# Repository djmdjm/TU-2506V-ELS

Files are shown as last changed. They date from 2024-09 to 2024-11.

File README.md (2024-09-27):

# Electronic Leadscrew for Optimum TU-2506V

This is a project to build an Electronic Leadscrew (ELS) for my bench
lathe, an Optimum TU-2506V. There are other lathes on the market that
seem to be based on the same casting (e.g. the Weiss WBL250F) that
might be compatible.

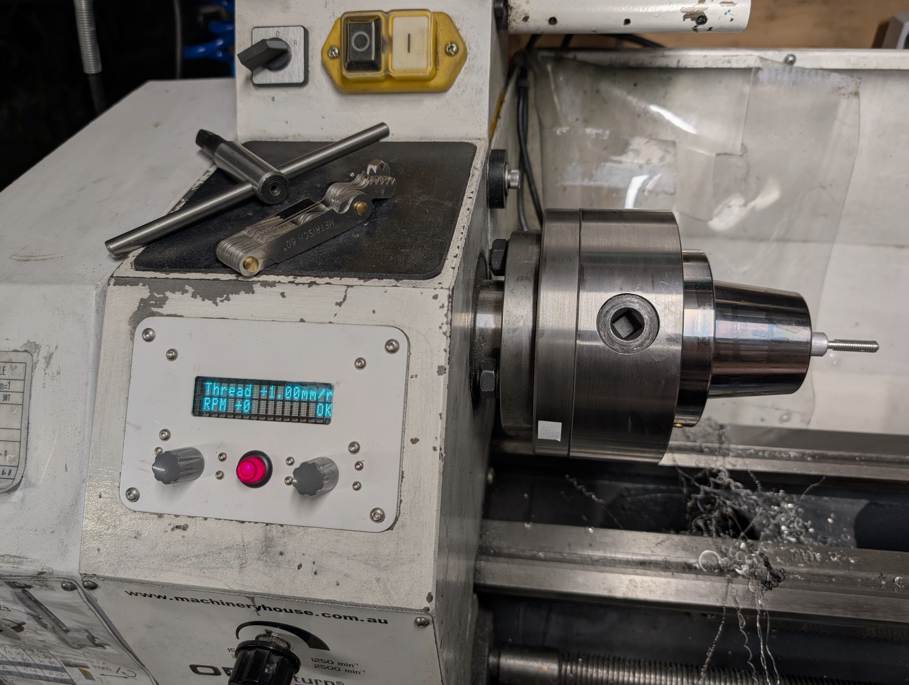
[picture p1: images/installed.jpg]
installed ELS controller


The project contains CAD designs for the mechanical parts, schematics,
PCB designs and firmware for the control board. More build photos
[here](https://photos.google.com/share/AF1QipOmF3oVsJtj0tLDA7D8ZUFRA7_QTG3Cf1XSVP2GjohUuVMBAQHxomHKcaGD1ETOJg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).

## Caveat

This works fine for me, but I'm just some guy on the internet with
little or no mechanical, electronic or software engineering training. 
There is no warranty for any of this, no guarantee that it will work,
no guarantee that it won't destroy your lathe, no promise that the
software won't crash in the middle of a job and scrap your part, etc.

Many of the mechanical pieces were manually made and even the
ones I CNC'd or had fabricated received some modifications that
aren't reflected in the CAD files. If you want to use this as the
basis of your own ELS, then be prepared to do some modifications of
your own.

## What you'll need (software)

The mechanical CAD designs were done in
[FreeCAD](https://www.freecad.org/) 0.21. For the parts that I CNC'd
myself, I also used FreeCAD's CAM processor to generate the G-Code.

The control boards was designed in [KiCAD](https://www.kicad.org/)
version 8 and were fabricated at JLCPCB. The PCB files have LCSC
annotations for automated assembly of the (few) SMT components.

The firmware for the control board was written in Rust using the
[stm32f4xx_hal](https://github.com/stm32-rs/stm32f4xx-hal) package.
I used rustc 1.81.0, but other versions might work too.

## What you'll need (hardware)

This lists only the main components. There are many small parts that
should be obvious from the CAD files, not to mention custom parts that
you'll need to make yourself or have fabricated.

The controller was designed around a
[STM32F411 "black pill"](https://www.dfrobot.com/product-2338.html) board.
These are also easily and cheaply available from hobbyist electronics
suppliers and from Ebay/Aliexpress.

The display is a
[Newhaven M0216SD‐162SDAR2-1](https://au.mouser.com/ProductDetail/Newhaven-Display/M0216SD-162SDAR2-1?qs=3vk7fz9CmNxwBN2LYkSmDA%3D%3D)
vacuum fluorescent display that I ordered from Mouser - this is a
fairly expensive part, but I love the aesthetics of a VFD.

The rest of the BOM for the controller can be extracted from the
KiCAD files for each of the respective boards. I mostly used parts that
I had on hand, so there are some odd choices in places.

The controller needs a 24VDC power supply at about 250mA in addition to
whatever the servo control needs. I used a Meanwell DIN rail mount PSU.

The servo motor I used a
[Teknic Clearpath CPM-SDSK-2331S-ELS](https://teknic.com/model-info/CPM-SDSK-2331S-ELS/).
Again, this is a fairly expensive choice and a cheaper stepper
motor + controller would probably do fine. The Clearpath drive does
have some very nice advantages over plain steppers or even cheap
closed-loop stepper drives. Whatever drive you choose, it obviously
needs to fit (NEMA 23 was close to the limit on my lathe) and you'll
need to provide a suitable power supply for it.

The spindle encoder I used was an
[Omron E6B2-CWZ1X](https://www.ia.omron.com/product/item/2382/). These are
ridiculously expensive if you buy them from anywhere reputable, but very
cheap on Ebay or Aliexpress.

The timing pulleys and belt used to connect the servo to the
leadscrew are standard HTD 5M parts. I got mine from PT Parts
([pulleys](https://www.ptparts.com.au/products/category/ALL/-12-5M-15--5m-15-htd-timing-pulleys):
20-5M-15F 40-5M-15F,
[belt](https://www.ptparts.com.au/products/category/ALL/-225-5M-15--5m-15-timing-belts): 350-5M-15),
but they should be fairly standard.

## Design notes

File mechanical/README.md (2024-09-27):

# CAD files for mechanical parts

This directory contains CAD files for some of the mechanical parts and
assemblies. They were all designed in FreeCAD 0.21. Some components
require plugins, e.g. the gears workbench and the fasteners workbench.

If you plan on using the CAM jobs included in some of the components,
you will definitiely need to change the machine model and tooling.

## Motor mounting plate

The `lathe_leadscrew_motor_plate.FCStd` file is the CAD for the servo
motor mounting plate. It's designed for a NEMA 23 servo or stepper.
It's a very basic part that is probably best laser-cut.

I did need to modify this plate a little to fit the space, but cutting
off a couple of the corners. This is not reflected in the CAD file.

This plate does double duty as a template to mark the locations of the
holes that need to be drilled and tapped into the lathe casting.

## Encoder assembly

The `lathe_leadscrew_encoder_plate.FCStd` is the assembly that couples
the encoder to the spindle. There's a few bespoke parts in here: a main
plate that holds the shaft bearing, a separate plate that mounts the
encoder, some standoffs to separate the two and a spindle that is driven
by a gear that couples to the spindle. Note the flexible coupler here
comes with the encoder.

I built the main plate as a weldment from laser-cut sheet metal and a
turned part that I then re-bored for concentricity on the CNC mill.

At first I used one of the original change gears on this assembly but,
like most change gears, it was annoyingly noisy. I ended up casting the
gear in polyurethane, which helped insofar as PU is better acoustically
than metal, but still wasn't amazing. If I ever rebuild the lathe spindle,
I'll replace the gear with another timing pulley.

## Controller assembly

`lathe_els_panel.FCStd` contains the CAD for the controller assembly, which
consists of a front panel in 2mm sheet metal, a protective lens machined from
2mm acrylic and a bunch of off-the-shelf standoffs and fasteners.

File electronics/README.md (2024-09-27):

# Controller schematics and PCB designs

This directory contains the schematics and PCB CAD files for the controller
boards. To fit in the available space in the lathe casting they are designed
as a stack.

The `mcu/` subdirectory contains the designs for the MCU carrier board, which
basically exists to route signals from the STM32F411 Black Pill board to the
adjacent ones via headers. The character VFD display also connects to this
board via extended headers.

The `pwr_io/` subdirectory has the design for the isolated power and I/O board.
It has a couple of modular DC-DC converters that provide an isolated supply
to the MCU and display, and a separate isolated supply for the spindle encoder
and servo control lines.

The `ui/` subdirectory has the design for the carrier board for the rotary
encoders used on the front panel (you'll need two of these). These connect
via cables terminated in IDC connectors on the MCU board.

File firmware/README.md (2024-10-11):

# Firmware for Electronic Leadscrew

This is the firmware for the electronic leadscrew controller board.
It's core task is receiving pulses from the encoder connected to the
lathe spindle and emitting pulses to drive the servo motor attached to
the lathe's leadscrew.

The user interface is a 16x2 VFD character display, two rotary encoders
with integrated pushbuttons and a dedicated pushbutton.

The firmware is written in Rust targetting the STM32F411 MCU. If you've
installed Rust using rustup, then you can get the toolchain and required
tools using:

```shell
rustup target add thumbv7em-none-eabihf
cargo install cargo-binutils
cargo install probe-rs-tools
```

For a good background on Rust embedded development, how to set up openocd,
install prerequisite system packages, etc. the
[Embedded Rust Book](https://docs.rust-embedded.org/book/) is a great start.

To build the firmware, run `cargo build` from this directory. If you have
the board attached using a ST-Link dongle and have `openocd` running,
then `cargo run` will attempt to download the firmware to the board and
run it under gdb. The `flash.sh` script will burn a release version of the
firmware to the board.

## Modes

The firmware supports a number of operating modes and a debug mode.
Switching between modes is done using one of the control rotary encoders,
with the other rotary encoder being used to set parameters within that mode
such as feed rate or thread pitch. Mode changes, and some parameter changes
will be ignored unless the spindle is stationery.

The controller starts in the `Servo off` mode, which unsurprisingly disables
the servo drive. The `Feed` mode is intended for general cutting applications,
and runs the leadscrew to advance at a configured rate (in mm) per spindle
revolution. Two threading modes are available: `Thread`, which performs metric
(mm/rev) threading and `Thread Im` which does imperial (TPI) threading.

The debug mode can be accessed by pressing the mode encoder's button for a
couple of seconds. This mode has a number of pages, accessible via the mode
wheel, that show various internal debugging parameters. Debug mode can be
exited by holding down the mode button again.

## Notes

The control loop for the ELS is quite simplistic - the mainloop runs
continuously and (depending on operating mode) generates servo control pulses
as quickly as it receives encoder pulses. It uses mostly-precomputed 64-bit
math to simplify (as 32.32 fixed point) to simplify calculations. Once of the
nice things about having a 100MHz MCU is not having to worry too much about
the cycle cost here.

There is one interrupt handler hooked up to one of the timers that runs a 1KHz
monotonic counter that is used to drive the 10Hz display update and the RPM
sampling/smoothing.

The most time-critical component of the firmware is the servo pulse generation.
At high RPM and high feed rates, the firmware needs to be able to quickly emit
lots of pulses. Conversely, the servo requires a maximum pulse frequency of
500KHz. I couldn't get this running fast enough in Rust, so the actual pulse
generation is written in assembly.

Motor, encoder, leadscrew and gear/pulley ratio constants are in `src/main.rs`.
You'll almost certainly need to edit these.

The calculations are unashamedly metric and inch leadscrews are not supported.

There's currently no detection of situations where the control loop can't keep
up (i.e. can't generate servo pulses fast enough for a given spindle RPM).
I'm fairly sure this situation isn't possible with the parameters I've used,
and I've certainly not encountered it in use (though admittedly I haven't
tried to run the leadscrew at 4mm/rev and 1500RPM).

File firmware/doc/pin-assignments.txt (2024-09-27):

Encoder inputs
PA0  - T2_CH1 - ENC1a (spindle)
PA1  - T2_CH2 - ENC1b (spindle)
PA6  - T9_CH1 - ENC2a (feed)
PA7  - T9_CH2 - ENC2b (feed)
PC15 - GPIOC  - ENC2 button (feed)
PB6  - T4_CH1 - ENC3a (mode)
PB7  - T4_CH2 - ENC3b (mode)
PB8  - GPIOB  - ENC3 button (mode)

Button inputs
PA4  - GPIOA  - Button 1

Other inputs
PA3 - GPIOA  - Motor HLFB input

Outputs
PC13 - GPIOC  - Board LED
PB10 - GPIOB  - Motor Enable output
PB1  - GPIOB  - Motor Direction output
PB0  - GPIOB  - Motor Step output

VFD I/O
PA15 - GPIOA  - DB0
PA12 - GPIOA  - DB1
PA8  - GPIOA  - DB2
PB14 - GPIOB  - DB3
PB13 - GPIOB  - DB4
PB12 - GPIOB  - DB5
PB15 - GPIOB  - DB6
PA11 - GPIOA  - DB7
PB4  - GPIOB  - E
PB9  - GPIOB  - RW
PB3  - GPIOB  - RS

Free
PA2  - GPIOA  -
PA5  - GPIOA  - 
PA9  - GPIOA  - TX1
PA10 - GPIOA  - RX1 (w/ 100k pull up to make BOOT0 reliable)
PB2  - GPIOB  -
PB5  - GPIOB  -
PC14 - GPIOC  - (nb. low current limit)

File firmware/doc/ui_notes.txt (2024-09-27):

Notes to plan UI on 16x2 character LCD/VFD.

available space

+----------------+
|0123456789abcdef|
|0123456789abcdef|
+----------------+

Normal feed mode

+----------------+
|Feed  +100μm/r  |
|RPM   3000    OK| (OK | WARN | ERR)
+----------------+

Constant feed mode

+----------------+
|Feed  +400mm/min|
|RPM   3000   ERR| (OK | WARN | ERR)
+----------------+

Threading mode (metric)

+----------------+
|Thread +1.00mm/R|
|RPM    300  WARN| (OK | WARN | ERR)
+----------------+

Threading mode (imperial)

+----------------+
|Thread +24TPI   |
|RPM    300    OK| (OK | WARN | ERR)
+----------------+

Slotting mode

+----------------+
|Slot   400mm/min|
|Depth  100mm RDY| (RDY | GO+ | GO- | ERR)
+----------------+

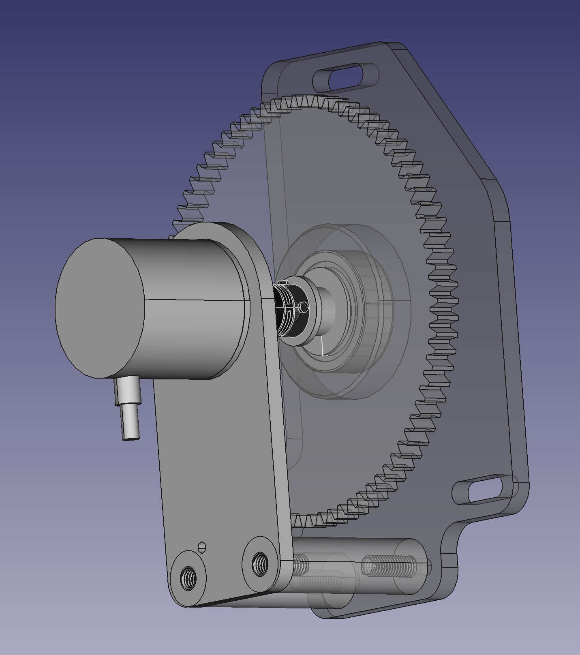
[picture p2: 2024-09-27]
mechanical/lathe_leadscrew_encoder_plate.png

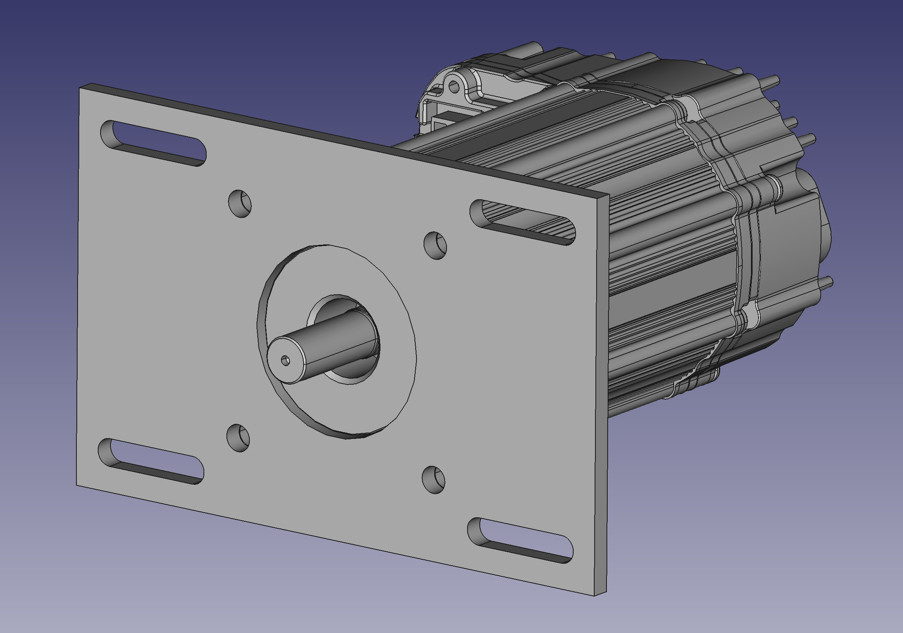
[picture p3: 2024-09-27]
mechanical/lathe_leadscrew_motor_plate.png

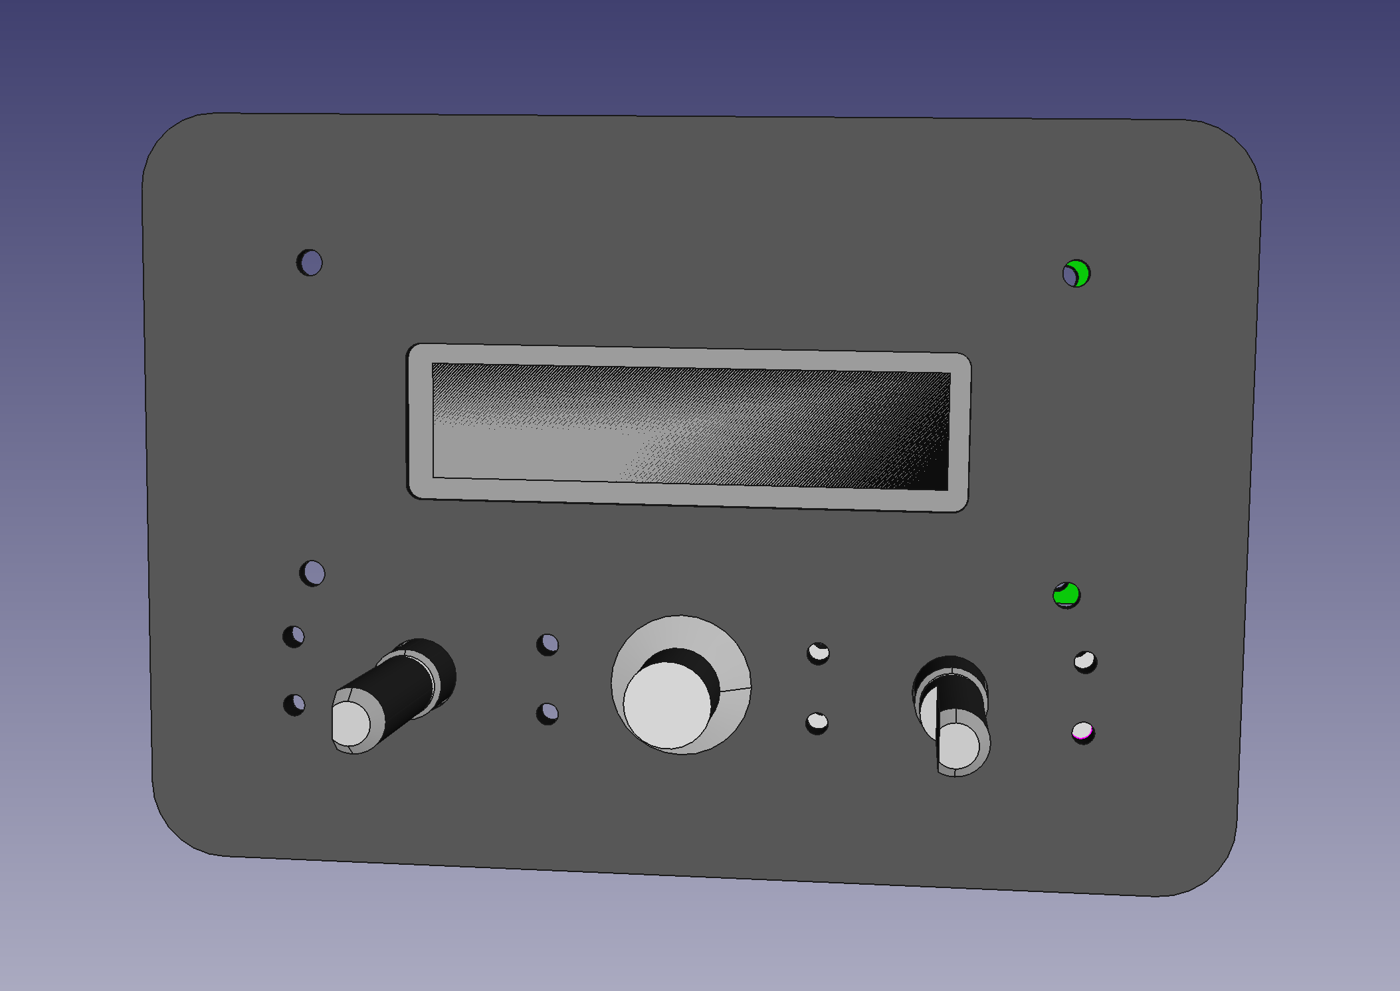
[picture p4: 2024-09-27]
mechanical/lathe_els_panel.png

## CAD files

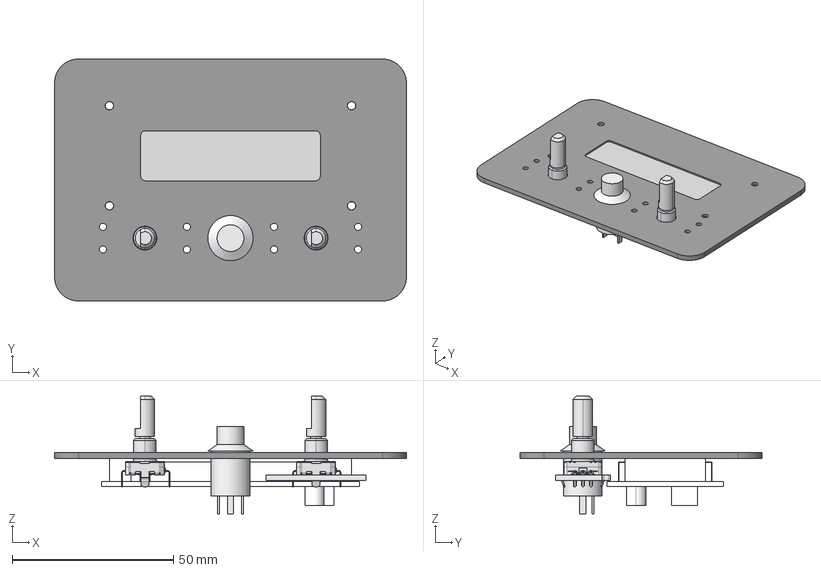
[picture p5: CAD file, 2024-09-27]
mechanical/lathe_els_panel.FCStd
109.0 x 75.0 x 36.5 mm
M0216SD-162SDAR2-1
Panel
Coverglass
Encoder1
Button
Encoder2
PCB

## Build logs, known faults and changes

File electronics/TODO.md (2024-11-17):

If I ever redesign the electronics, here are changes to make:

* Use vertical entry screw terminals so ferrules can clear lathe casting.
* More spare GPIO inputs/outputs.
* Another spare encoder channel would be nice too...
* Use JST-style connectors for encoders/button; IDC sockets were a fail.
* GPIO to control button light.
* Isolated RS-485 for spindle motor control and telemetry.
* See if I can cram everything onto one bespoke board.

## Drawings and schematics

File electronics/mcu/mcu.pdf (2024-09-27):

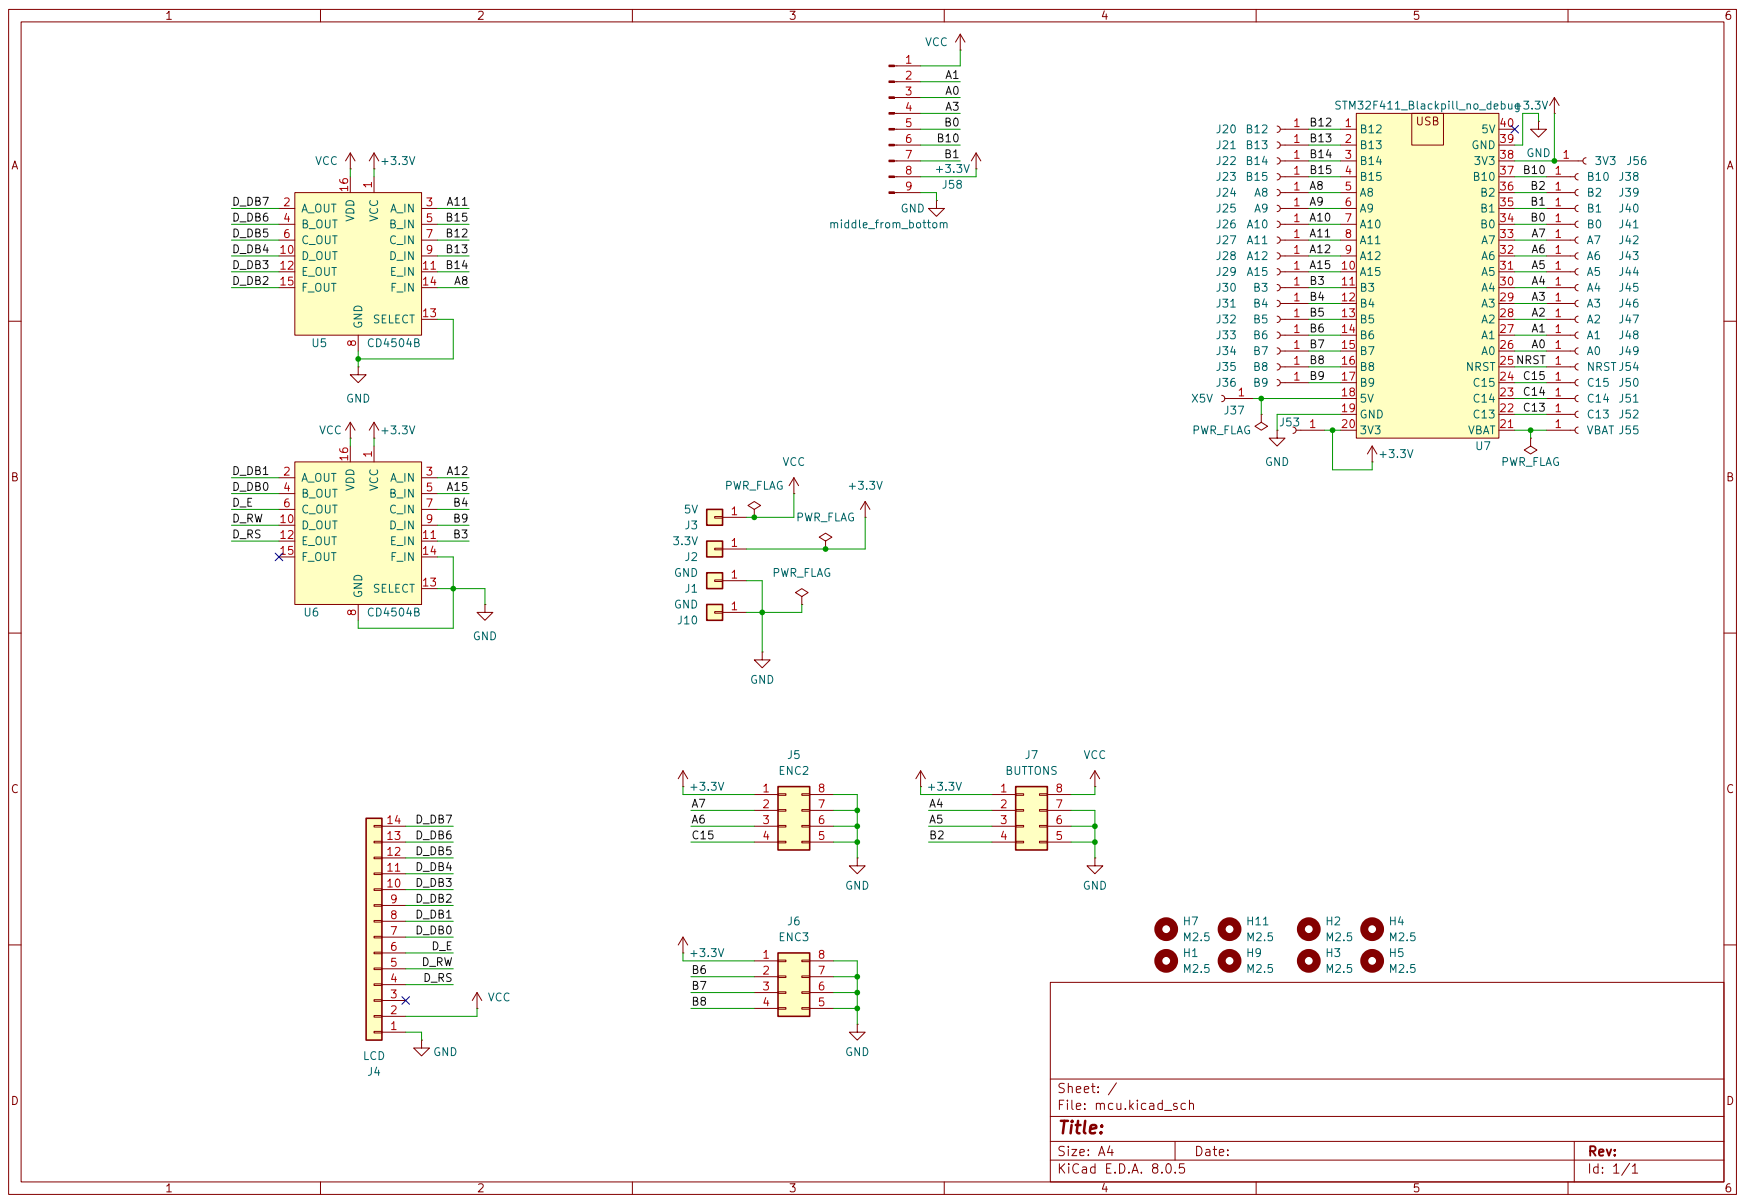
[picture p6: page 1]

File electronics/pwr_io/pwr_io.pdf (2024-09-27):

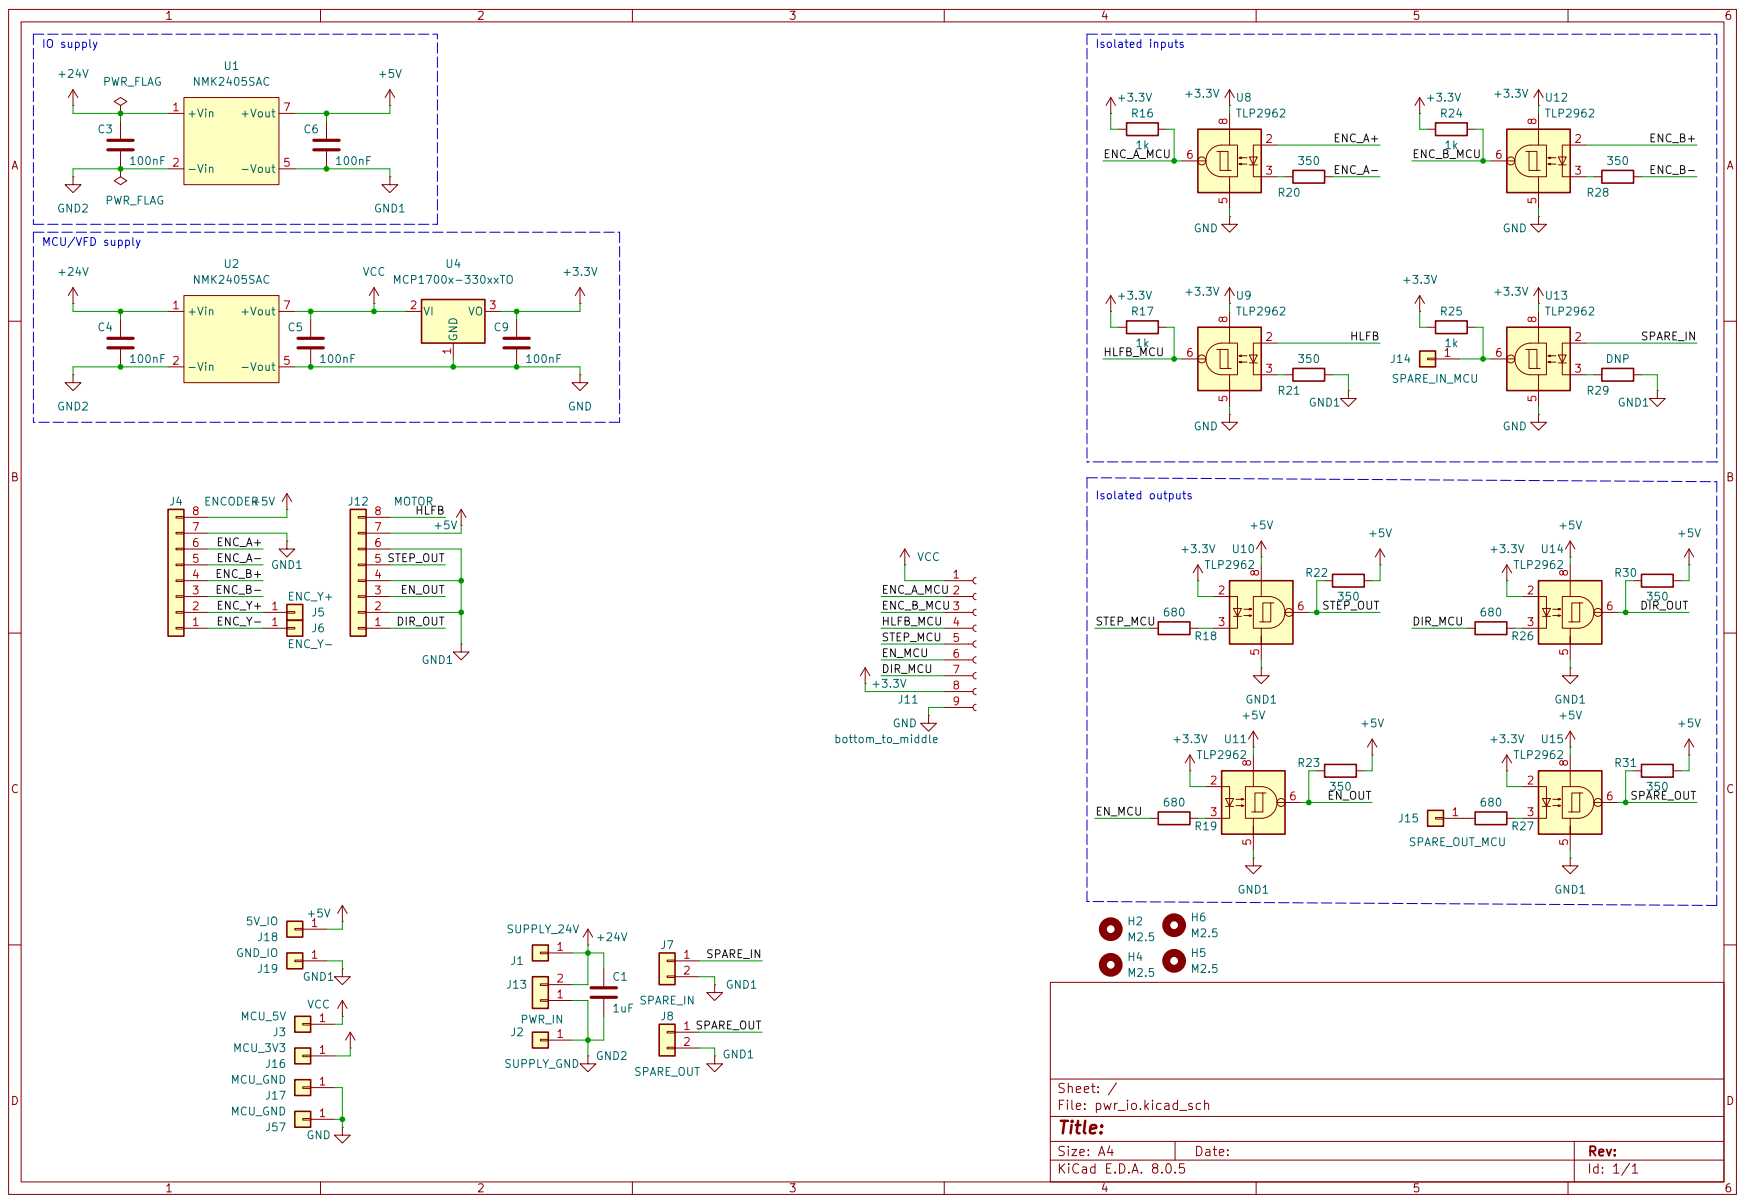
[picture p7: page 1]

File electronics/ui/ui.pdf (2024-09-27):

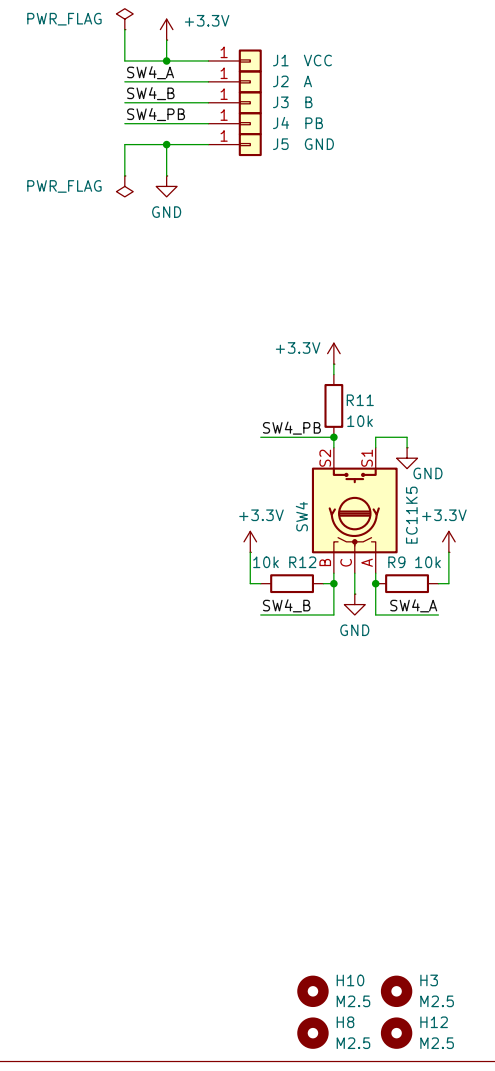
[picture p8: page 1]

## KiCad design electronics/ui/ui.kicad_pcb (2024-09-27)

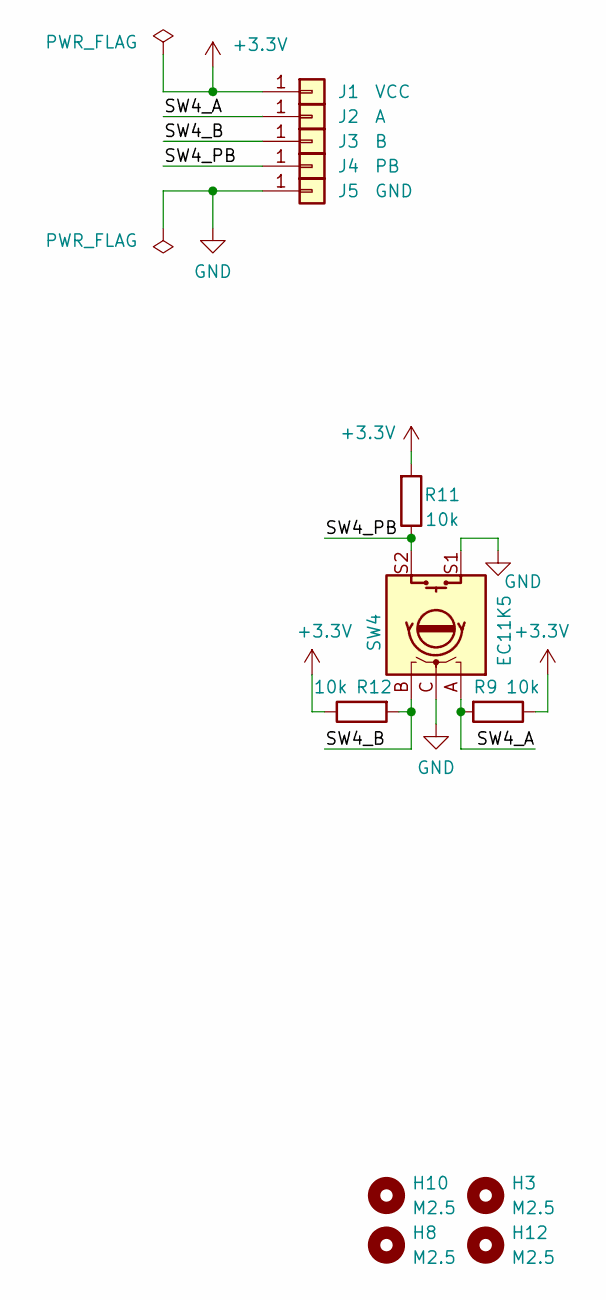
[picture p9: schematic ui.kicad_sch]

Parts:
H3, H8, H10, H12: M2.5; MountingHole_2.2mm_M2
J1: VCC; TestPoint_THTPad_D1.0mm_Drill0.5mm
J2: A; TestPoint_THTPad_D1.0mm_Drill0.5mm
J3: B; TestPoint_THTPad_D1.0mm_Drill0.5mm
J4: PB; TestPoint_THTPad_D1.0mm_Drill0.5mm
J5: GND; TestPoint_THTPad_D1.0mm_Drill0.5mm
R9, R11, R12: 10k; R_0805_2012Metric; LCSC C17414
SW4: EC11K5; EC11K15

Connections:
+3.3V: J1.1, R9.1, R11.2, R12.1
/SW4_A: J2.1, R9.2, SW4.A
/SW4_B: J3.1, R12.2, SW4.B
/SW4_PB: J4.1, R11.1, SW4.S2
GND: J5.1, SW4.C, SW4.S1

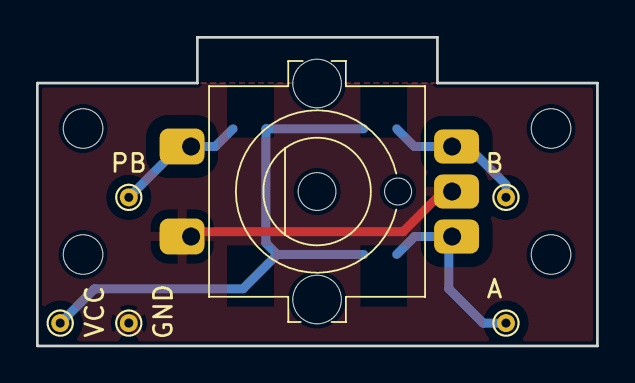
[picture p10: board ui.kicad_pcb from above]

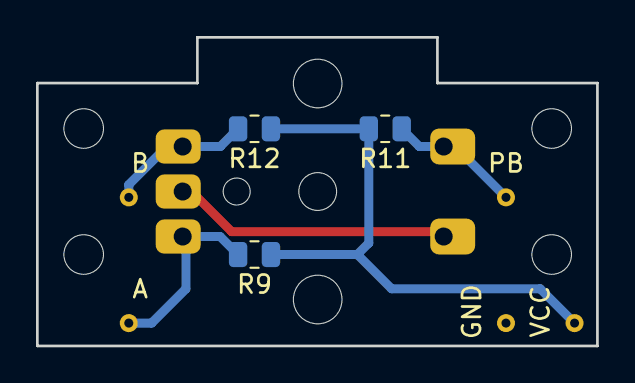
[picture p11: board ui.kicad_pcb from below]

Board: 2 copper layers, 31.1 x 17.1 mm, 13 parts (3 on the bottom side), 5 nets.

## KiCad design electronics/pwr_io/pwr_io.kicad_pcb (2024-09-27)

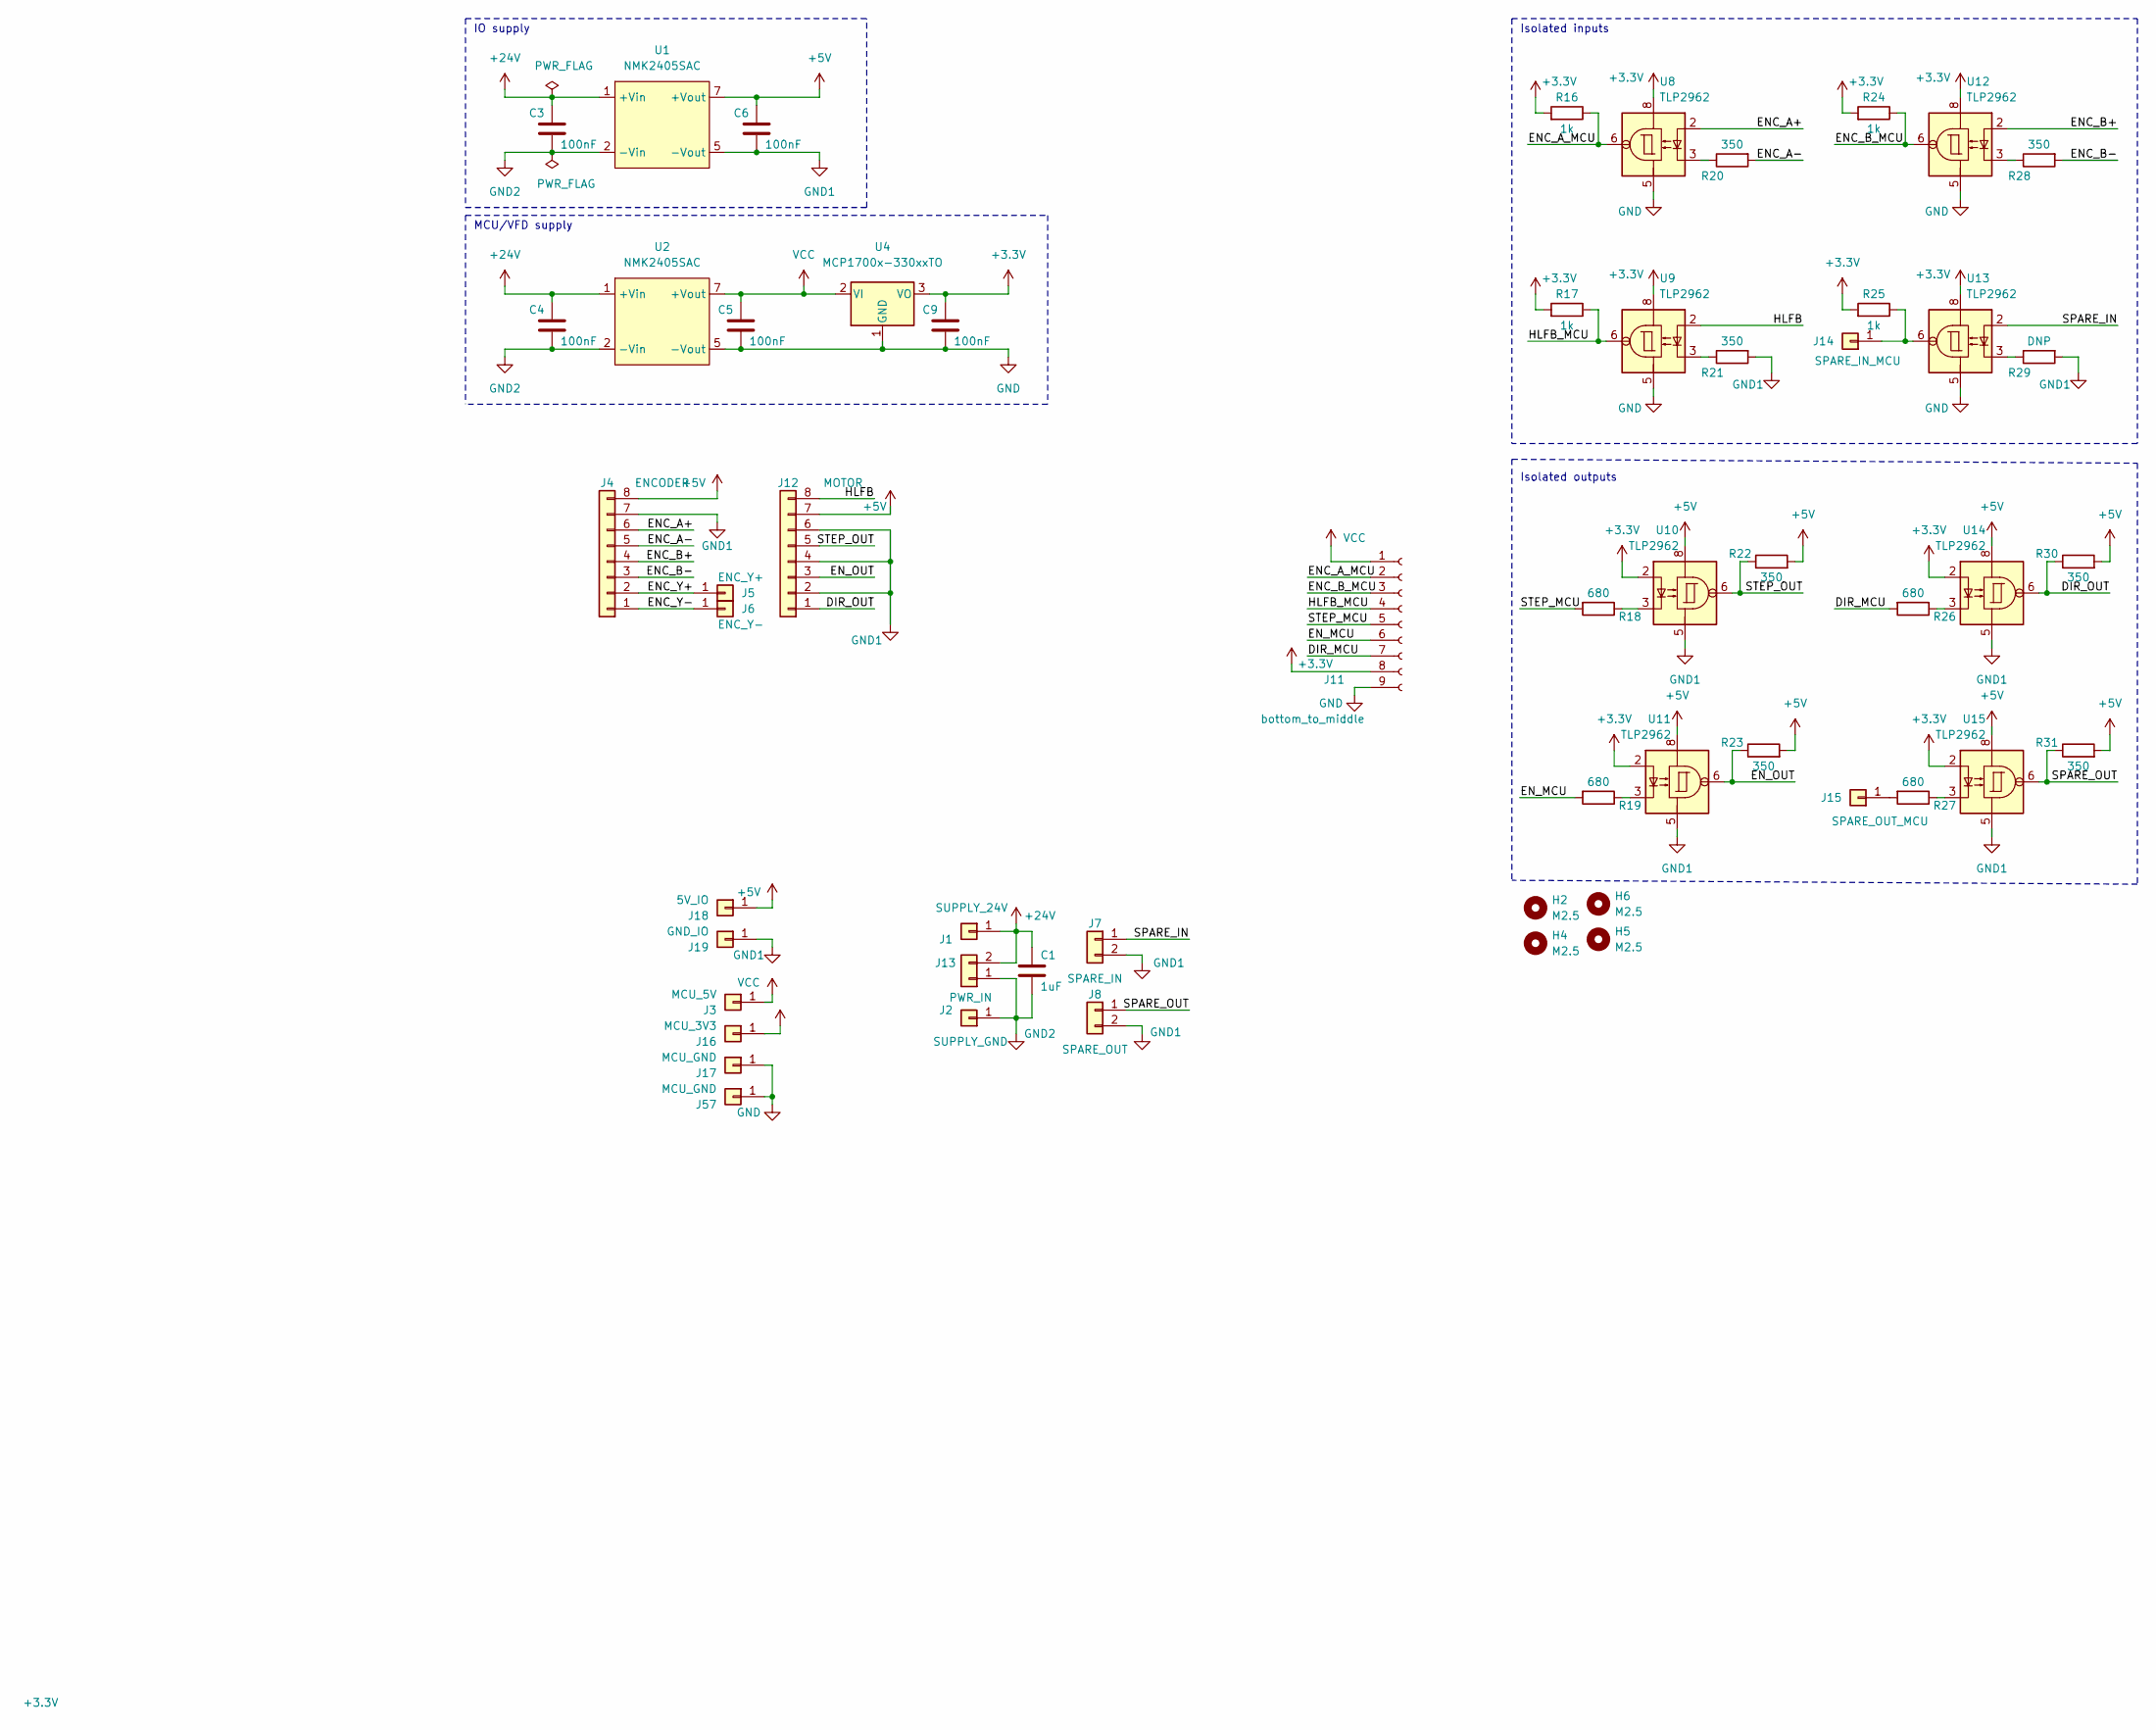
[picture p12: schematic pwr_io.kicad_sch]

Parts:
C1: 1uF; C_0805_2012Metric; LCSC C28323
C3, C4, C5, C6, C9: 100nF; C_0805_2012Metric; LCSC C28233
H2, H4, H5, H6: M2.5; MountingHole_2.7mm_M2.5
J1: SUPPLY_24V; TestPoint_THTPad_D1.5mm_Drill0.7mm
J2: SUPPLY_GND; TestPoint_THTPad_D1.5mm_Drill0.7mm
J3: MCU_5V; TestPoint_THTPad_D1.5mm_Drill0.7mm
J4: ENCODER; TerminalBlock_Phoenix_MKDS-1,5-8_1x08_P5.00mm_Horizontal
J5: ENC_Y+; TestPoint_THTPad_D1.5mm_Drill0.7mm
J6: ENC_Y-; TestPoint_THTPad_D1.5mm_Drill0.7mm
J7: SPARE_IN; TerminalBlock_Phoenix_MKDS-1,5-2_1x02_P5.00mm_Horizontal
J8: SPARE_OUT; TerminalBlock_Phoenix_MKDS-1,5-2_1x02_P5.00mm_Horizontal
J11: bottom_to_middle; PinHeader_1x09_P2.54mm_Vertical
J12: MOTOR; TerminalBlock_Phoenix_MKDS-1,5-8_1x08_P5.00mm_Horizontal
J13: PWR_IN; TerminalBlock_Phoenix_MKDS-1,5-2_1x02_P5.00mm_Horizontal
J14: SPARE_IN_MCU; TestPoint_THTPad_D1.5mm_Drill0.7mm
J15: SPARE_OUT_MCU; TestPoint_THTPad_D1.5mm_Drill0.7mm
J16: MCU_3V3; TestPoint_THTPad_D1.5mm_Drill0.7mm
J17, J57: MCU_GND; TestPoint_THTPad_D1.5mm_Drill0.7mm
J18: 5V_IO; TestPoint_THTPad_D1.5mm_Drill0.7mm
J19: GND_IO; TestPoint_THTPad_D1.5mm_Drill0.7mm
R16, R17, R24, R25: 1k; R_0805_2012Metric; LCSC C17513
R18, R19, R26, R27: 680; R_0805_2012Metric; LCSC C93658
R20, R21, R22, R23, R28, R30, R31: 350; R_0805_2012Metric; LCSC C245312
R29: DNP; R_0805_2012Metric
U1, U2: NMK2405SAC; NMK_single_output
U4: MCP1700x-330xxTO; TO-92_Inline
U8, U9, U10, U11, U12, U13, U14, U15: TLP2962; DIP-8_W7.62mm

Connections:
+3.3V: C9.1, J11.8, J16.1, R16.2, R17.2, R24.2, R25.2, U4.3 (VO), U8.8, U9.8, U10.2, U11.2, U12.8, U13.8, U14.2, U15.2
+5V: C6.1, J4.8, J12.7, J18.1, R22.2, R23.2, R30.2, R31.2, U1.7 (+Vout), U10.8, U11.8, U14.8, U15.8
+24V: C1.1, C3.1, C4.1, J1.1, J13.2, U1.1 (+Vin), U2.1 (+Vin)
/DIR_MCU: J11.7, R26.2
/DIR_OUT: J12.1, R30.1, U14.6
/ENC_A+: J4.6, U8.2
/ENC_A-: J4.5, R20.2
/ENC_A_MCU: J11.2, R16.1, U8.6
/ENC_B+: J4.4, U12.2
/ENC_B-: J4.3, R28.2
/ENC_B_MCU: J11.3, R24.1, U12.6
/ENC_Y+: J4.2, J5.1
/ENC_Y-: J4.1, J6.1
/EN_MCU: J11.6, R19.2
/EN_OUT: J12.3, R23.1, U11.6
/HLFB: J12.8, U9.2
/HLFB_MCU: J11.4, R17.1, U9.6
/SPARE_IN: J7.1, U13.2
/SPARE_OUT: J8.1, R31.1, U15.6
/STEP_MCU: J11.5, R18.2
/STEP_OUT: J12.5, R22.1, U10.6
GND: C5.2, C9.2, J11.9, J17.1, J57.1, U2.5 (-Vout), U4.1 (GND), U8.5, U9.5, U12.5, U13.5
GND1: C6.2, J4.7, J7.2, J8.2, J12.2, J12.4, J12.6, J19.1, R21.2, R29.2, U1.5 (-Vout), U10.5, U11.5, U14.5, U15.5
GND2: C1.2, C3.2, C4.2, J2.1, J13.1, U1.2 (-Vin), U2.2 (-Vin)
unnamed: J14.1, R25.1, U13.6
unnamed: J15.1, R27.2
unnamed: R18.1, U10.3
unnamed: R19.1, U11.3
unnamed: R20.1, U8.3
unnamed: R21.1, U9.3
unnamed: R26.1, U14.3
unnamed: R27.1, U15.3
unnamed: R28.1, U12.3
unnamed: R29.1, U13.3
VCC: C5.1, J3.1, J11.1, U2.7 (+Vout), U4.2 (VI)

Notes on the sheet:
Isolated outputs
Isolated inputs
IO supply
MCU/VFD supply

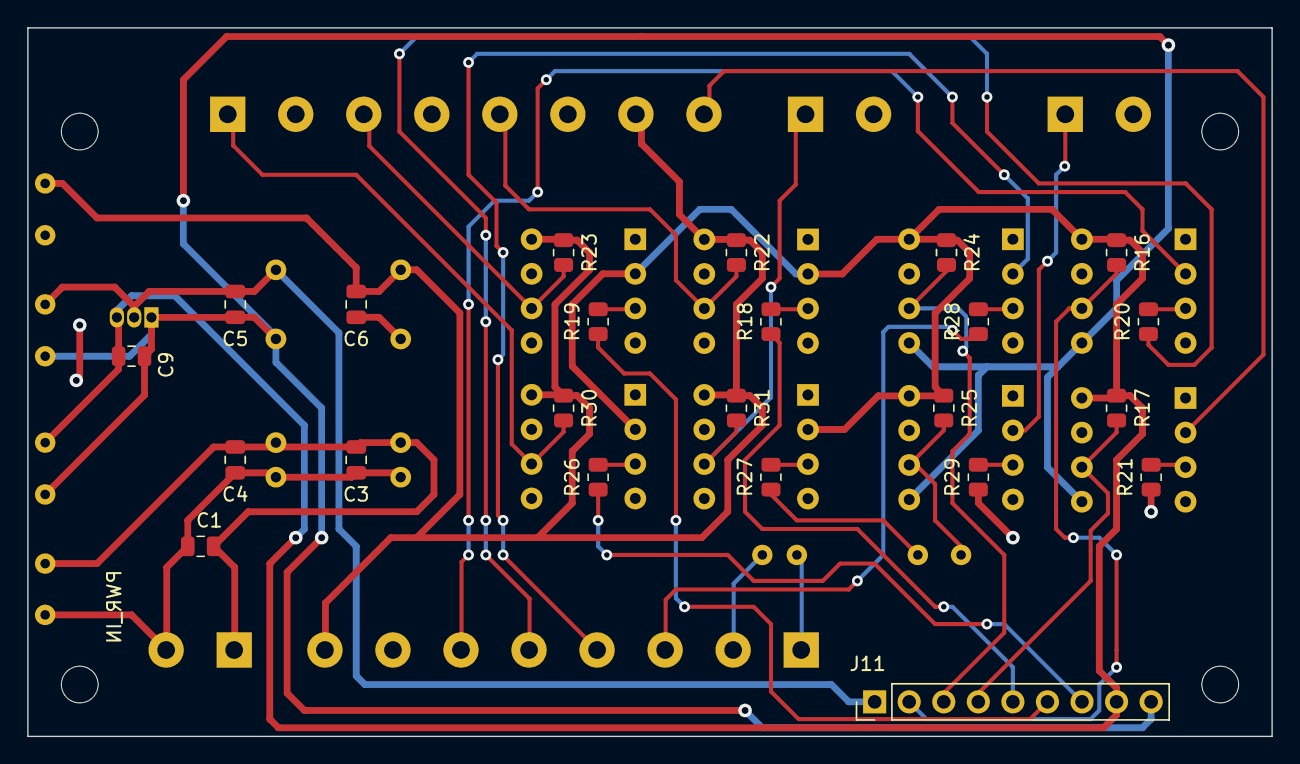
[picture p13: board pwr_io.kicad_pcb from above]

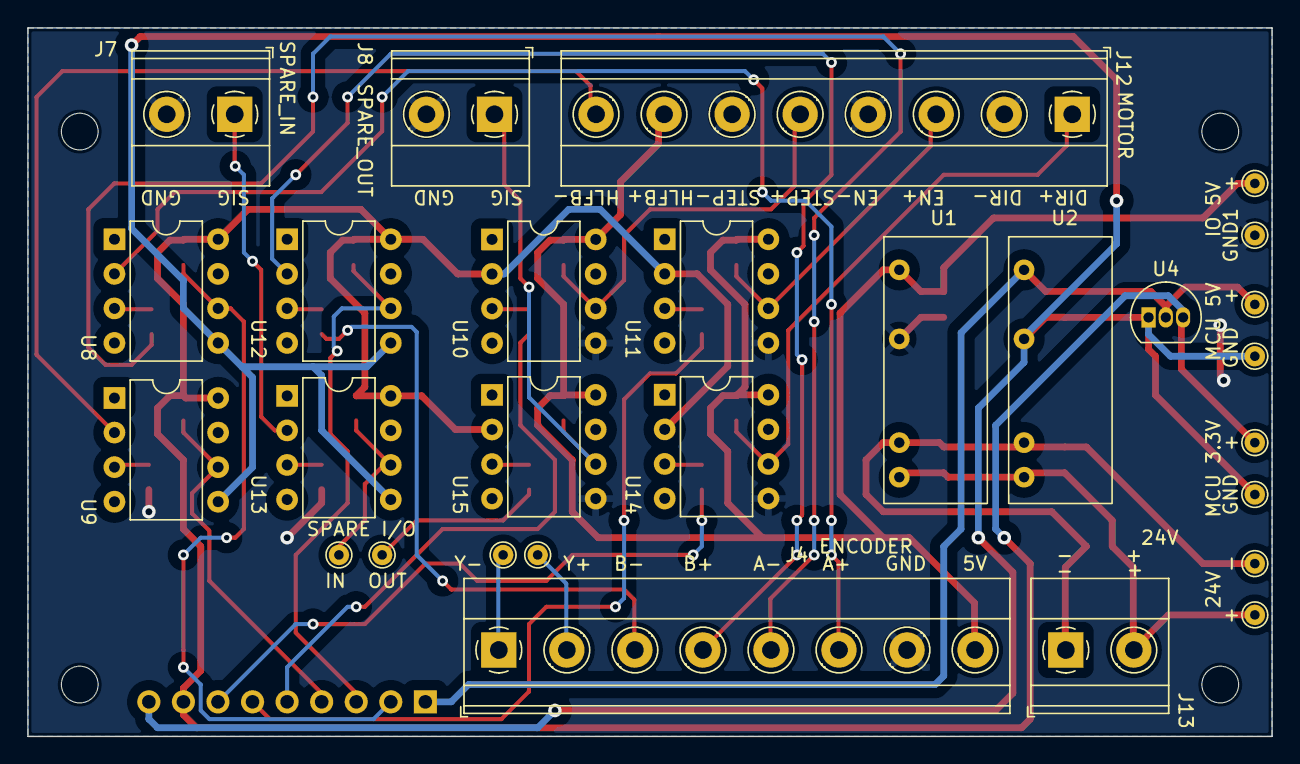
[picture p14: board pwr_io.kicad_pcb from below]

Board: 2 copper layers, 91.4 x 52.1 mm, 55 parts (28 on the bottom side), 35 nets.

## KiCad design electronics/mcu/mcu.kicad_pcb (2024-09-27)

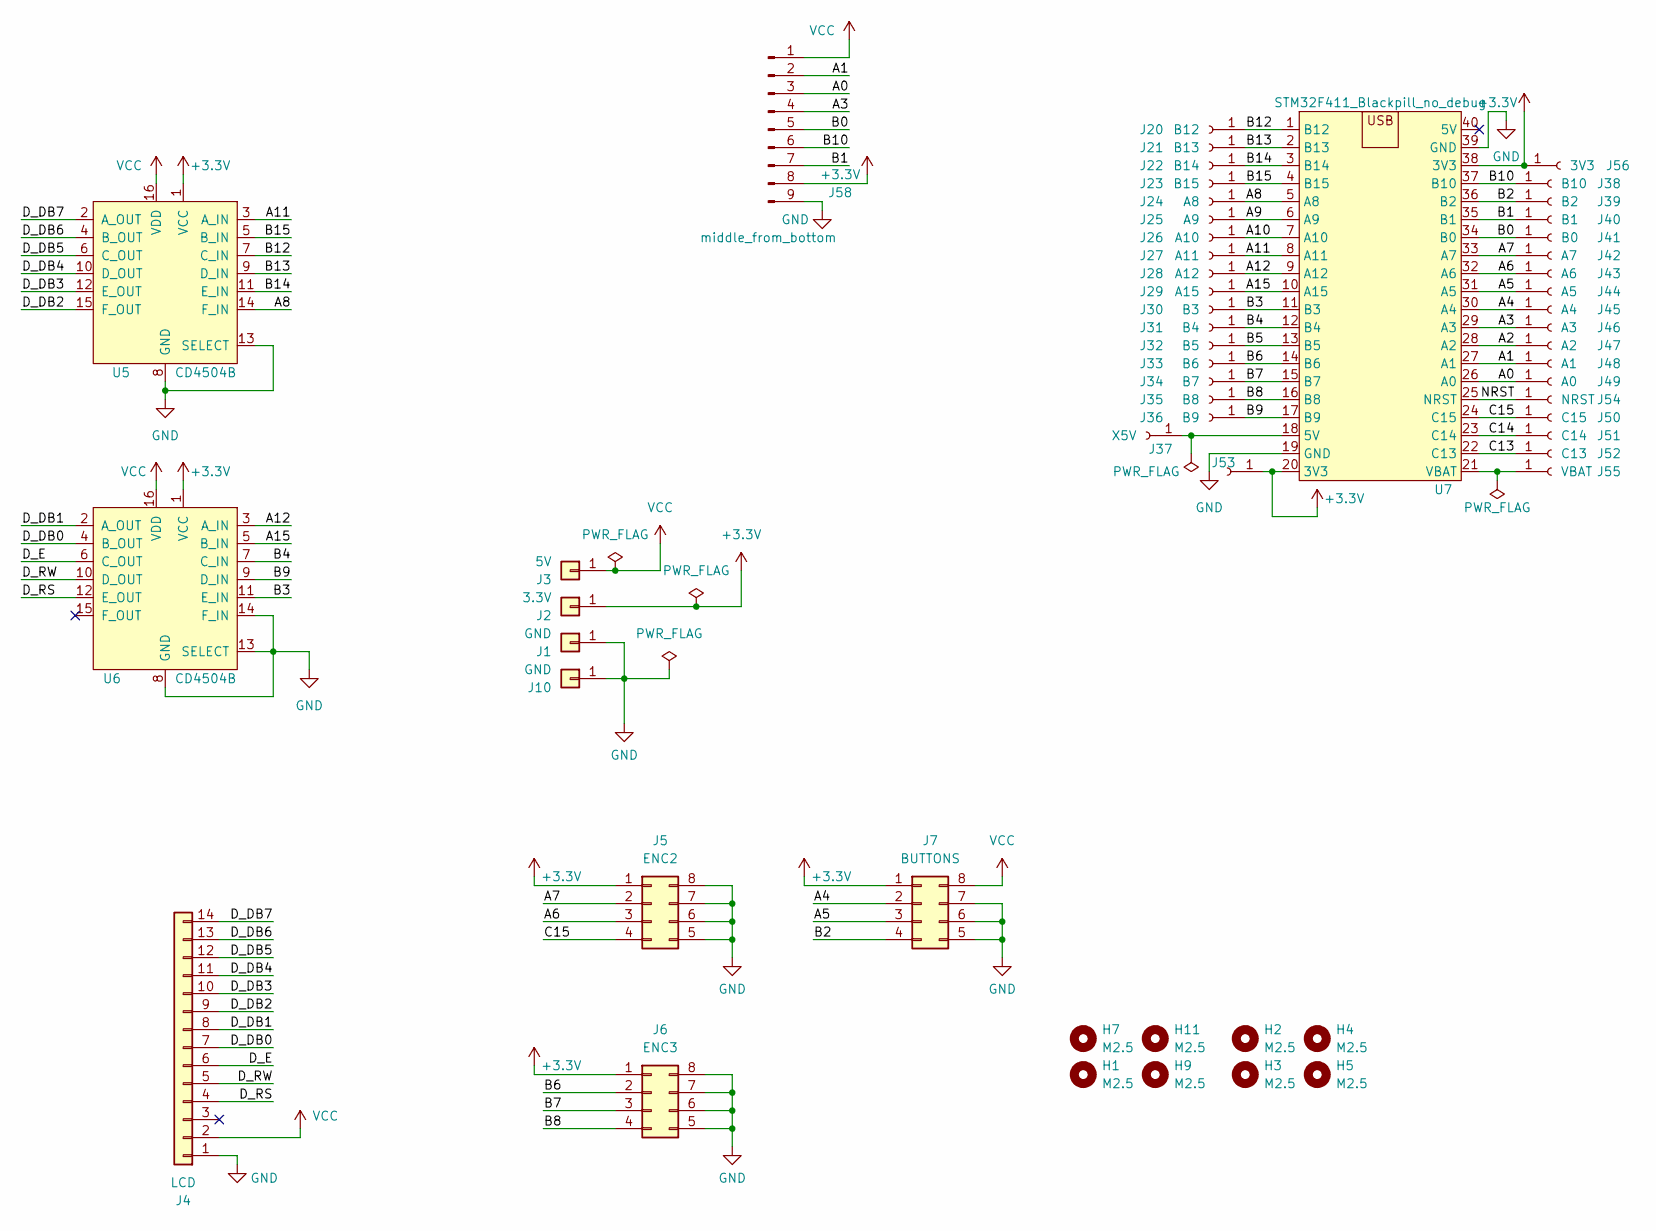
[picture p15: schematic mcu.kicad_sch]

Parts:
H1, H2, H3, H4, H5, H7, H9, H11: M2.5; MountingHole_2.7mm_M2.5
J1, J10: GND; TestPoint_THTPad_D1.5mm_Drill0.7mm
J2: 3.3V; TestPoint_THTPad_D1.5mm_Drill0.7mm
J3: 5V; TestPoint_THTPad_D1.5mm_Drill0.7mm
J4: LCD; PinHeader_1x14_P2.54mm_Vertical
J5: ENC2; IDC-Header_2x04_P2.54mm_Vertical
J6: ENC3; IDC-Header_2x04_P2.54mm_Vertical
J7: BUTTONS; IDC-Header_2x04_P2.54mm_Vertical
J20: B12; TestPoint_THTPad_D1.5mm_Drill0.7mm
J21: B13; TestPoint_THTPad_D1.5mm_Drill0.7mm
J22: B14; TestPoint_THTPad_D1.5mm_Drill0.7mm
J23: B15; TestPoint_THTPad_D1.5mm_Drill0.7mm
J24: A8; TestPoint_THTPad_D1.5mm_Drill0.7mm
J25: A9; TestPoint_THTPad_D1.5mm_Drill0.7mm
J26: A10; TestPoint_THTPad_D1.5mm_Drill0.7mm
J27: A11; TestPoint_THTPad_D1.5mm_Drill0.7mm
J28: A12; TestPoint_THTPad_D1.5mm_Drill0.7mm
J29: A15; TestPoint_THTPad_D1.5mm_Drill0.7mm
J30: B3; TestPoint_THTPad_D1.5mm_Drill0.7mm
J31: B4; TestPoint_THTPad_D1.5mm_Drill0.7mm
J32: B5; TestPoint_THTPad_D1.5mm_Drill0.7mm
J33: B6; TestPoint_THTPad_D1.5mm_Drill0.7mm
J34: B7; TestPoint_THTPad_D1.5mm_Drill0.7mm
J35: B8; TestPoint_THTPad_D1.5mm_Drill0.7mm
J36: B9; TestPoint_THTPad_D1.5mm_Drill0.7mm
J37: X5V; TestPoint_THTPad_D1.5mm_Drill0.7mm
J38: B10; TestPoint_THTPad_D1.5mm_Drill0.7mm
J39: B2; TestPoint_THTPad_D1.5mm_Drill0.7mm
J40: B1; TestPoint_THTPad_D1.5mm_Drill0.7mm
J41: B0; TestPoint_THTPad_D1.5mm_Drill0.7mm
J42: A7; TestPoint_THTPad_D1.5mm_Drill0.7mm
J43: A6; TestPoint_THTPad_D1.5mm_Drill0.7mm
J44: A5; TestPoint_THTPad_D1.5mm_Drill0.7mm
J45: A4; TestPoint_THTPad_D1.5mm_Drill0.7mm
J46: A3; TestPoint_THTPad_D1.5mm_Drill0.7mm
J47: A2; TestPoint_THTPad_D1.5mm_Drill0.7mm
J48: A1; TestPoint_THTPad_D1.5mm_Drill0.7mm
J49: A0; TestPoint_THTPad_D1.5mm_Drill0.7mm
J50: C15; TestPoint_THTPad_D1.5mm_Drill0.7mm
J51: C14; TestPoint_THTPad_D1.5mm_Drill0.7mm
J52: C13; TestPoint_THTPad_D1.5mm_Drill0.7mm
J53, J56: 3V3; TestPoint_THTPad_D1.5mm_Drill0.7mm
J54: NRST; TestPoint_THTPad_D1.5mm_Drill0.7mm
J55: VBAT; TestPoint_THTPad_D1.5mm_Drill0.7mm
J58: middle_from_bottom; PinSocket_1x09_P2.54mm_Vertical
U5, U6: CD4504B; DIP-16_W7.62mm
U7: STM32F411_Blackpill_no_debug; BlackPill_V3_no_debug

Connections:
+3.3V: J2.1, J5.1, J6.1, J7.1, J53.1, J56.1, J58.8, U5.1 (VCC), U6.1 (VCC), U7.20 (3V3), U7.38 (3V3)
/A0: J49.1, J58.3, U7.26 (A0)
/A1: J48.1, J58.2, U7.27 (A1)
/A2: J47.1, U7.28 (A2)
/A3: J46.1, J58.4, U7.29 (A3)
/A4: J7.2, J45.1, U7.30 (A4)
/A5: J7.3, J44.1, U7.31 (A5)
/A6: J5.3, J43.1, U7.32 (A6)
/A7: J5.2, J42.1, U7.33 (A7)
/A8: J24.1, U5.14 (F_IN), U7.5 (A8)
/A9: J25.1, U7.6 (A9)
/A10: J26.1, U7.7 (A10)
/A11: J27.1, U5.3 (A_IN), U7.8 (A11)
/A12: J28.1, U6.3 (A_IN), U7.9 (A12)
/A15: J29.1, U6.5 (B_IN), U7.10 (A15)
/B0: J41.1, J58.5, U7.34 (B0)
/B1: J40.1, J58.7, U7.35 (B1)
/B2: J7.4, J39.1, U7.36 (B2)
/B3: J30.1, U6.11 (E_IN), U7.11 (B3)
/B4: J31.1, U6.7 (C_IN), U7.12 (B4)
/B5: J32.1, U7.13 (B5)
/B6: J6.2, J33.1, U7.14 (B6)
/B7: J6.3, J34.1, U7.15 (B7)
/B8: J6.4, J35.1, U7.16 (B8)
/B9: J36.1, U6.9 (D_IN), U7.17 (B9)
/B10: J38.1, J58.6, U7.37 (B10)
/B12: J20.1, U5.7 (C_IN), U7.1 (B12)
/B13: J21.1, U5.9 (D_IN), U7.2 (B13)
/B14: J22.1, U5.11 (E_IN), U7.3 (B14)
/B15: J23.1, U5.5 (B_IN), U7.4 (B15)
/C13: J52.1, U7.22 (C13)
/C14: J51.1, U7.23 (C14)
/C15: J5.4, J50.1, U7.24 (C15)
/D_DB0: J4.7, U6.4 (B_OUT)
/D_DB1: J4.8, U6.2 (A_OUT)
/D_DB2: J4.9, U5.15 (F_OUT)
/D_DB3: J4.10, U5.12 (E_OUT)
/D_DB4: J4.11, U5.10 (D_OUT)
/D_DB5: J4.12, U5.6 (C_OUT)
/D_DB6: J4.13, U5.4 (B_OUT)
/D_DB7: J4.14, U5.2 (A_OUT)
/D_E: J4.6, U6.6 (C_OUT)
/D_RS: J4.4, U6.12 (E_OUT)
/D_RW: J4.5, U6.10 (D_OUT)
/NRST: J54.1, U7.25 (NRST)
GND: J1.1, J4.1, J5.5, J5.6, J5.7, J5.8, J6.5, J6.6, J6.7, J6.8, J7.5, J7.6, J7.7, J10.1, J58.9, U5.8 (GND), U5.13 (SELECT), U6.8 (GND), U6.13 (SELECT), U6.14 (F_IN), U7.19 (GND), U7.39 (GND)
unnamed: J37.1, U7.18 (5V)
unnamed: J55.1, U7.21 (VBAT)
VCC: J3.1, J4.2, J7.8, J58.1, U5.16 (VDD), U6.16 (VDD)

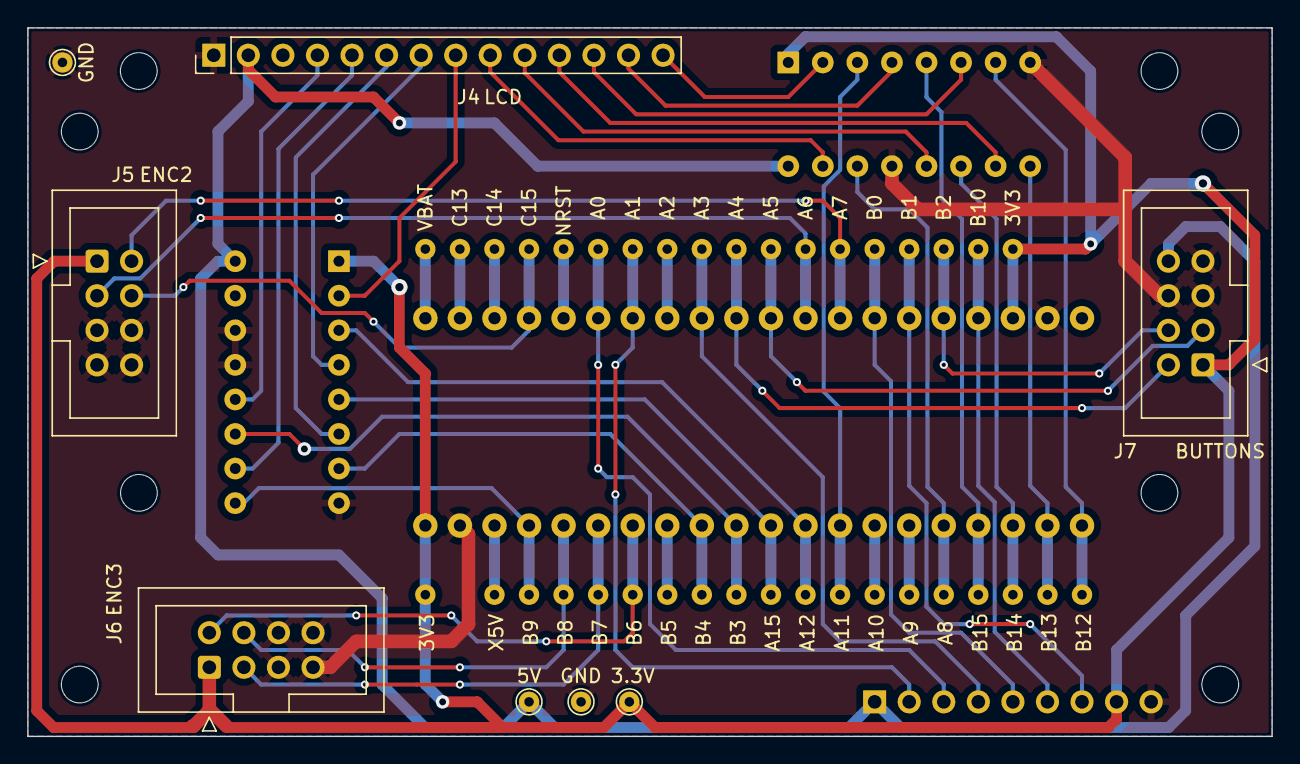
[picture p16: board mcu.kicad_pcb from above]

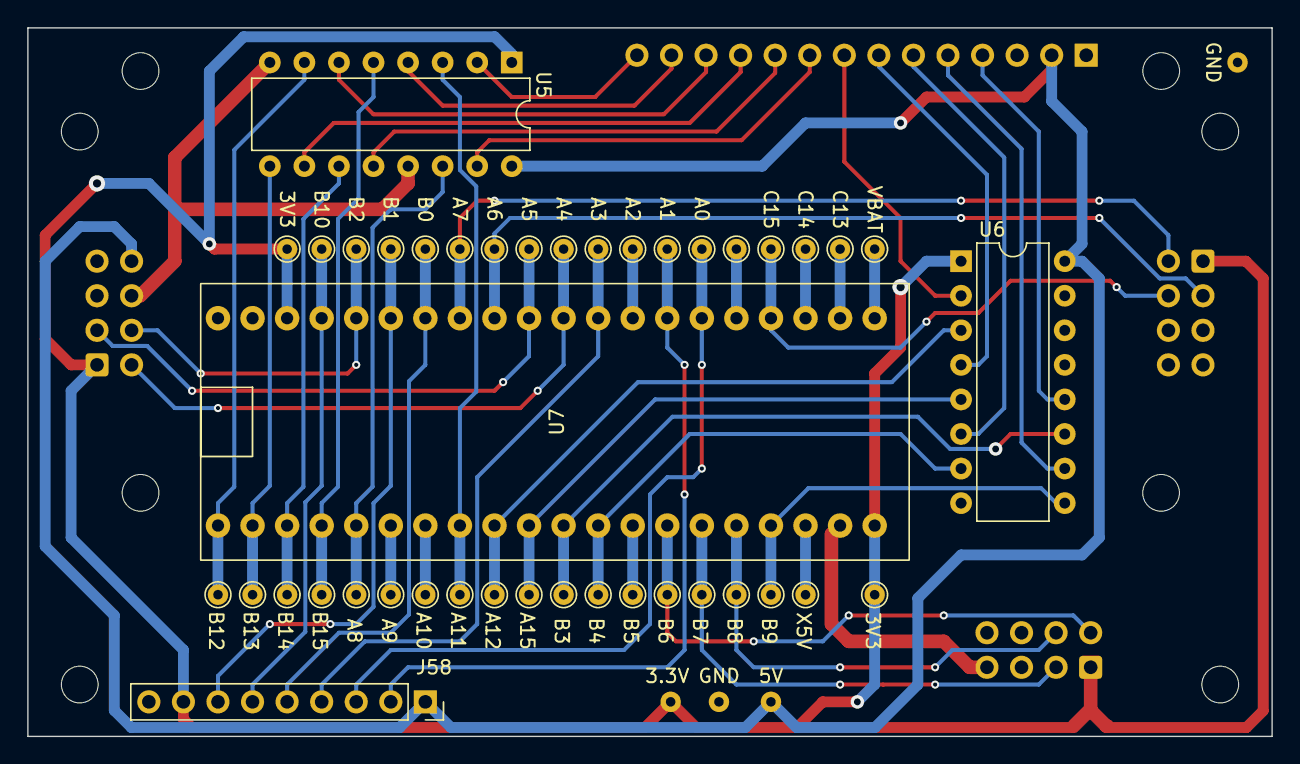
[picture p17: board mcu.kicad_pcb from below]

Board: 2 copper layers, 91.4 x 52.1 mm, 57 parts (41 on the bottom side), 49 nets.

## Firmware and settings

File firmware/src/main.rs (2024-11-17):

#![no_std]
#![no_main]

//use panic_probe as _;
use panic_halt as _;
use stm32f4xx_hal as hal;

mod lcd;
use lcd::*;
mod control;
mod fir;
mod userinterface;
use userinterface::Mode;
mod pulse;
use pulse::Pulser;

use core::cell::{Cell, RefCell};
use core::fmt::Write;
//use cortex_m::asm::delay;
use cortex_m::interrupt::Mutex;
use cortex_m_rt::entry;
//use cortex_m_semihosting::hprintln;
use hal::dwt::DwtExt;
use hal::gpio::Speed;
use hal::pac;
use hal::pac::interrupt;
use hal::prelude::*;
use hal::qei::Qei;
use hal::timer::{CounterUs, Event};

const ENCODER_PPR: i64 = 2000;
const ENCODER_RATIO_SPINDLE: i64 = -40;
const ENCODER_RATIO_ENCODER: i64 = 80;

const LEADSCREW_PITCH: i64 = 3000; // µm
const DRIVE_RATIO_MOTOR: i64 = -20;
const DRIVE_RATIO_LEADSCREW: i64 = 80; // 40 tooth pulley and x0.5 gearbox.

const MOTOR_PPR: i64 = 3200;

const UI_ENCODER_PULSE_PER_DETENT: u32 = 2;
const DISPLAY_UPDATE_RATE: u32 = 10; // Hz

const RPM_SMOOTH_UPDATE_RATE: u32 = 50; // Hz
const RPM_SMOOTH_DISPLAY_RATE: u32 = DISPLAY_UPDATE_RATE; // Hz
const RPM_SMOOTH_FIR_DEPTH: usize = 20;

type Fir = fir::FirFilter<RPM_SMOOTH_FIR_DEPTH>;
static G_RPM: Mutex<Cell<i32>> = Mutex::new(Cell::new(0));
static G_ENC: Mutex<Cell<i32>> = Mutex::new(Cell::new(0));
static G_NOW: Mutex<Cell<i64>> = Mutex::new(Cell::new(0));
static G_TIM: Mutex<RefCell<Option<CounterUs<pac::TIM5>>>> = Mutex::new(RefCell::new(None));

#[interrupt]
fn TIM5() {
    // Take static reference to counter.
    static mut TIM: Option<CounterUs<pac::TIM5>> = None;
    let tim = TIM.get_or_insert_with(|| {
        cortex_m::interrupt::free(|cs| G_TIM.borrow(cs).replace(None).unwrap())
    });

    let mut ms: i64 = 0;
    static RPM_FIR: Mutex<RefCell<Fir>> = Mutex::new(RefCell::new(Fir::new()));
    cortex_m::interrupt::free(|cs| {
        // Update monotonic millisecond counter.
        let now = G_NOW.borrow(cs);
        // Yes, this will fail after a few thousand centuries of uptime.
        // I'll fix it closer to then.
        ms = now.get().saturating_add(1);
        now.set(ms);
        // Calculate a FIR-smoothed RPM value every RPM_SMOOTH_UPDATE_RATE Hz.
        if ms % (1000 / RPM_SMOOTH_UPDATE_RATE) as i64 == 0 {
            let enc = G_ENC.borrow(cs);
            RPM_FIR.borrow(cs).borrow_mut().update(enc.get());
            enc.set(0);
        }
        if ms % (1000 / RPM_SMOOTH_DISPLAY_RATE) as i64 == 0 {
            let mut val = RPM_FIR.borrow(cs).borrow().filtered_value() as i64;
            // 'val' is average encoder pulses per interval over the FIR
            // period; convert this to RPM.
            val *= RPM_SMOOTH_UPDATE_RATE as i64; // pulses per second.
            val *= 60; // pulses per minute.
            val = (val * ENCODER_RATIO_SPINDLE) / ENCODER_RATIO_ENCODER;
            val /= ENCODER_PPR; // RPM
            G_RPM.borrow(cs).set(val as i32);
        }
    });

    let _ = tim.wait();
}

#[entry]
fn main() -> ! {
    //hprintln!("start");
    let dp = pac::Peripherals::take().unwrap();
    let cp = cortex_m::peripheral::Peripherals::take().unwrap();
    let rcc = dp.RCC.constrain();

    let gpioa = dp.GPIOA.split();
    let gpiob = dp.GPIOB.split();
    let gpioc = dp.GPIOC.split();

    let clocks = rcc
        .cfgr
        .use_hse(25.MHz())
        .sysclk(100.MHz())
        .hclk(25.MHz())
        .freeze();

    let dwt = cp.DWT.constrain(cp.DCB, &clocks);
    let mut ns_delay = dwt.delay();
    let mut timer = dp.TIM5.counter_us(&clocks);
    let mut delay = dp.TIM9.delay_us(&clocks);

    // Start the timer to give us a 1kHz clock interrupt.
    timer.start(1.millis()).unwrap();
    timer.listen(Event::Update);
    cortex_m::interrupt::free(|cs| *G_TIM.borrow(cs).borrow_mut() = Some(timer));
    unsafe {
        cortex_m::peripheral::NVIC::unmask(pac::Interrupt::TIM5);
    }

    // Encoders and associated switches.
    let spindle_enc = Qei::new(dp.TIM2, (gpioa.pa0, gpioa.pa1));
    let feed_enc = Qei::new(dp.TIM3, (gpioa.pa6, gpioa.pa7));
    let mode_enc = Qei::new(dp.TIM4, (gpiob.pb6, gpiob.pb7));
    let feed_enc_sw = gpioc.pc15.into_input();
    let mode_enc_sw = gpiob.pb8.into_input();

    // Control buttons.
    let button1 = gpioa.pa4.into_input();

    // Optocoupled inputs.
    let servo_ok_in = gpioa.pa3.into_input();

    // LED outputs.
    let mut board_led = gpioc.pc13.into_push_pull_output();

    // Optocoupled outputs.
    let mut motor_enable_out = gpiob.pb10.into_push_pull_output();
    let mut motor_dir_out = gpiob.pb1.into_push_pull_output();
    let mut motor_step_out = gpiob.pb0.into_push_pull_output().erase_number();

    // Display I/O.
    let mut disp_rs = gpiob.pb3.into_push_pull_output().speed(Speed::Medium);
    let mut disp_rw = gpiob.pb9.into_push_pull_output().speed(Speed::Medium);
    let mut disp_e = gpiob.pb4.into_push_pull_output().speed(Speed::Medium);
    let mut disp_db0 = gpioa.pa15.into_push_pull_output().speed(Speed::Medium);
    let mut disp_db1 = gpioa.pa12.into_push_pull_output().speed(Speed::Medium);
    let mut disp_db2 = gpioa.pa8.into_push_pull_output().speed(Speed::Medium);
    let mut disp_db3 = gpiob.pb14.into_push_pull_output().speed(Speed::Medium);
    let mut disp_db4 = gpiob.pb13.into_push_pull_output().speed(Speed::Medium);
    let mut disp_db5 = gpiob.pb12.into_push_pull_output().speed(Speed::Medium);
    let mut disp_db6 = gpiob.pb15.into_push_pull_output().speed(Speed::Medium);
    let mut disp_db7 = gpioa.pa11.into_push_pull_output().speed(Speed::Medium);
    let mut display = lcd::Display8Bit::new(
        &mut disp_rs,
        &mut disp_rw,
        &mut disp_e,
        &mut disp_db0,
        &mut disp_db1,
        &mut disp_db2,
        &mut disp_db3,
        &mut disp_db4,
        &mut disp_db5,
        &mut disp_db6,
        &mut disp_db7,
        &mut ns_delay,
    );
    display.init();
    write!(display.at(6, 0), "hello").ok();
    write!(display.at(6, 1), "there!").ok();
    delay.delay_ms(500u32);
    display.clear();
    motor_dir_out.set_low();
    motor_enable_out.set_low();
    motor_step_out.set_low();
    let mut pulser = Pulser::new(&mut motor_step_out);
    let mut cold: bool = true;
    let mut last_ms: i64 = 0;
    let mut now_ms: i64 = 0;
    let mut next_ui_ms: i64 = 0;
    let mut spindle_enc_count = spindle_enc.count() as i32;
    let mut spindle_enc_last = spindle_enc_count;
    let mut spindle_enc_delta: i32 = 0;
    let mut smoothed_rpm: i32 = 0;
    let mut ui = userinterface::UI::new(&mut display);
    let mut control = control::Control::new();
    let mut last_motor_dir: bool = false;
    let mut last_motor_enable: bool = false;
    let mut motor_pulses_since_last_ui: u32 = 0;
    loop {
        // Twiddle board LED as heartbeat.
        board_led.set_state((now_ms % 200 < 100).into());

        cortex_m::interrupt::free(|cs| {
            // Calculate number/direction of spindle encoder pulses.
            spindle_enc_count = spindle_enc.count() as i32;
            spindle_enc_delta = spindle_enc_count - spindle_enc_last;
            spindle_enc_last = spindle_enc_count;
            // Update global encoder pulse accumulator.
            let enc = G_ENC.borrow(cs);
            enc.set(enc.get() + spindle_enc_delta);
            // Get global millisecond counter and smoothed RPM value.
            now_ms = G_NOW.borrow(cs).get();
            smoothed_rpm = G_RPM.borrow(cs).get();
        });

        // Calculate elapsed ms since last loop iteration.
        let mut ms_elapsed: u32 = 0;
        if cold {
            cold = false;
        } else {
            ms_elapsed = (now_ms - last_ms).try_into().unwrap_or(0);
        }
        last_ms = now_ms;

        // Servo OK input is inverted.
        let servo_ok: bool = servo_ok_in.is_low();

        if next_ui_ms < now_ms {
            ui.update(
                &mut control,
                now_ms,
                smoothed_rpm,
                servo_ok,
                button1.is_high(),
                mode_enc.count() as i16,
                mode_enc_sw.is_low(),
                feed_enc.count() as i16,
                feed_enc_sw.is_low(),
                spindle_enc_count,
                motor_pulses_since_last_ui,
                last_motor_enable,
                last_motor_dir,
            );
            next_ui_ms = now_ms + (1000 / DISPLAY_UPDATE_RATE as i64);
            motor_pulses_since_last_ui = 0;
        }
        // Call controller for current mode to determine motor commands.
        let mut motor_enable: bool = false;
        let mut motor_dir: bool = false;
        let mut motor_pulses: u32 = 0;
        match ui.get_mode() {
            Mode::ServoOff => (),
            Mode::Feed | Mode::ThreadMetric | Mode::ThreadImperial => {
                // Prepare to command drive based on spindle motion and/or time.
                let (direction, pulses) = control.feed_per_rev(spindle_enc_delta, ms_elapsed);
                motor_dir = direction.into();
                motor_pulses = pulses;
                motor_enable = true;
            }
        }
        // Changes in enable and direction require at least 1μs to
        // be recognised.
        if last_motor_enable != motor_enable {
            motor_enable_out.set_state(motor_enable.into());
            delay.delay_us(2);
            last_motor_enable = motor_enable;
        }
        // Don't bother sending pulses if the drive has alarmed or is disabled.
        if !servo_ok || !motor_enable {
            continue;
        }
        if motor_dir != last_motor_dir {
            motor_dir_out.set_state(motor_dir.into());
            delay.delay_us(2);
            last_motor_dir = motor_dir;
        }
        // XXX warning if we're not keeping up.
        pulser.pulse(motor_pulses);
        motor_pulses_since_last_ui += motor_pulses;
    }
}

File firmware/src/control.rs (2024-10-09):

//! Encoder/Servo control

#[derive(Clone, Copy)]
pub enum Direction {
    Forward,
    Backwards,
}

impl From<Direction> for bool {
    fn from(val: Direction) -> Self {
        match val {
            Direction::Forward => true,
            Direction::Backwards => false,
        }
    }
}

pub struct Control {
    // XXX direction?
    feed_rate_micron_per_rev: i32,

    feed_per_rev_factor: i64,
    fractional_pulses_remaining: i64,
    last_direction: Direction,
}

impl Control {
    pub fn new() -> Self {
        Control {
            feed_rate_micron_per_rev: 0,
            feed_per_rev_factor: 0,
            fractional_pulses_remaining: 0,
            last_direction: Direction::Forward,
        }
    }
    pub fn feed_per_rev(
        &mut self,
        encoder_pulses: i32,
        _elapsed_ms: u32,
    ) -> (Direction, u32) {
        let mut t: i64 = encoder_pulses as i64 * self.feed_per_rev_factor;
        t += self.fractional_pulses_remaining;
        // Retain remainder for next round.
        let mut pulses: i32 = (t >> 32) as i32;
        t -= (pulses as i64) << 32;
        self.fractional_pulses_remaining = t;
        let mut direction: Direction = self.last_direction;
        #[allow(clippy::comparison_chain)]
        if pulses > 0 {
            direction = Direction::Forward;
        } else if pulses < 0 {
            pulses = -pulses;
            direction = Direction::Backwards;
        }
        self.last_direction = direction;
        // XXX acceleration and deceleration control.
        // XXX hystereis for direction control.
        (direction, pulses as u32)
    }
    pub fn get_feed_rate_micron_per_rev(&self) -> i32 {
        self.feed_rate_micron_per_rev
    }
    pub fn get_last_direction(&self) -> Direction {
        self.last_direction
    }
    pub fn get_fractional_pulses_remaining(&self) -> i64 {
        self.fractional_pulses_remaining
    }
    pub fn set_feed_rate_micron_per_rev(&mut self, feed: i32) {
        // XXX bounds checking.
        self.feed_rate_micron_per_rev = feed;
        self.fractional_pulses_remaining = 0;
        // XXX consider fixed point split; is 32.32 ideal?
        // Precalculate multiplication factor.
        // Pulses to fractional turns (32.32 fixed point).
        let mut t: i64 = 1 << 32;
        t *= crate::ENCODER_RATIO_SPINDLE;
        t /= crate::ENCODER_PPR * crate::ENCODER_RATIO_ENCODER;
        // Encoder turns to fractional leadscrew turns (32.32).
        t *= self.feed_rate_micron_per_rev as i64;
        t *= crate::DRIVE_RATIO_LEADSCREW;
        t /= crate::DRIVE_RATIO_MOTOR * crate::LEADSCREW_PITCH;
        // Leadscrew turns to encoder pulses (32.32).
        t *= crate::MOTOR_PPR;
        self.feed_per_rev_factor = t
    }
    pub fn set_feed_rate_tpi(&mut self, tpi: i32) {
        // XXX bounds checking.
        self.feed_rate_micron_per_rev = 2540/tpi; // Approximation only.
        self.fractional_pulses_remaining = 0;
        // XXX consider fixed point split; is 32.32 ideal?
        // Precalculate multiplication factor.
        // Pulses to fractional turns (32.32 fixed point).
        let mut t: i64 = 1 << 32;
        t *= crate::ENCODER_RATIO_SPINDLE;
        t /= crate::ENCODER_PPR * crate::ENCODER_RATIO_ENCODER;
        // Encoder turns to fractional leadscrew turns (32.32).
        t *= 25400;
        t /= tpi as i64;
        t *= crate::DRIVE_RATIO_LEADSCREW;
        t /= crate::DRIVE_RATIO_MOTOR * crate::LEADSCREW_PITCH;
        // Leadscrew turns to encoder pulses (32.32).
        t *= crate::MOTOR_PPR;
        self.feed_per_rev_factor = t
    }
}

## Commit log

2024-10-09 improve TPI threading mode
    Use full range of 32.32 fixed point math for TPI feed rate rather
    than microns/rev approximation.
    [control.rs, userinterface.rs]
2024-11-17 bugfix: reentering Servo Off didn't disable servo
    [main.rs]
2024-11-17 bug: Servo Off incorrectly displayed servo error
    [userinterface.rs]
2024-11-17 ui tweaks for safety
    Require the mode encoder button to be depressed to change mode.
    Likewise, require the feed button to be depressed to change thread
    pitch.
    Found out the hard way that it's fairly easy to bump a control knob
    during a threading operation.
    Move debug mode to requiring both mode+feed encoder buttons be held
    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
